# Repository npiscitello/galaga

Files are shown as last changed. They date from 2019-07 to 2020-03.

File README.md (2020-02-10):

# Sample Rate
If we run the system on the 8MHz internal clock and use 8-bit resolution PWM for the audio, we'll
have a sample rate of 8000000/256=31250 Hz. I used Audacity to prepare the audio files - project
rate of 31250, split into mono and delete one channel, then export the audio to unsigned 8 bit raw.

# FAT Driver
FatFS driver - see http://elm-chan.org/fsw/ff/00index_e.html (may take a while to load)

# KiCAD
Required libraries (may not be an all-inclusive list...):
 * custom library, bundled in this repo
 * Device
 * Connector
 * MCU_Microchip_ATmega
 * Amplifier_Audio
 * Regulator_Linear

# Random Number Generator
This project needs some way to decide which sound to play. The easy way out is
to just play one sound over and over, but I wanted more variety. I could rotate
over a list of sounds sequentially, but then I'd have to store which sound
played previously in the EEPROM and worry about wear leveling and all sorts of
mess, so I decided to just choose a random sound every time the chip starts up.
This also has the added bonus of not getting locked into a monotonous loop if
you want to play a few sounds in a row.

On the advice of a few threads over at AVRFreaks, I played around with using ADC
noise as an entropy source for a random number generator. I tried using the
internal temp sensor, but it ended up working much better to use ADC5, the pin
furthest from the GND pin. It probably didn't matter which pin I used (not that
I tested pin vs. pin performance), but it seemed like that was a free way to get
a little bit more noise on the line. That's a weird sentence to type, but noise
is desirable in this case!

The random number generator itself is dead simple - I read the two LSBs of the
ADC four times to fill an 8 bit unsigned int then just modulo that number with
the number of entries in my sound file array. That number is just an index into
that array and bam - random sound. See `code/main_code/sound_files.c` for the
implementation.

To test the randomness I cycled the chip 100 times and recorded the output of
the RNG. The histogram of the results is shown below - not the most even
distribution but certainly random enough for my purposes. This test also
doubled as a stability test, and I'm happy to report that it ran flawlessly,
with no errors or hiccups, all 100 times in a row!

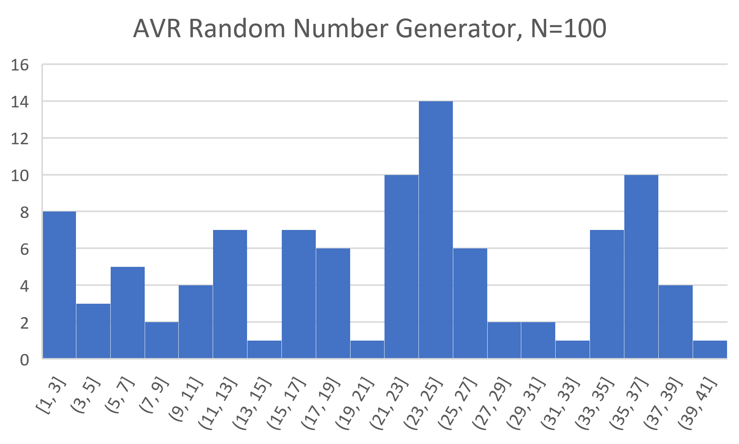
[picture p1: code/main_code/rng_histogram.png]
Histogram showing the results of 100 test runs of the RNG. The distribution is satisfactorily random.


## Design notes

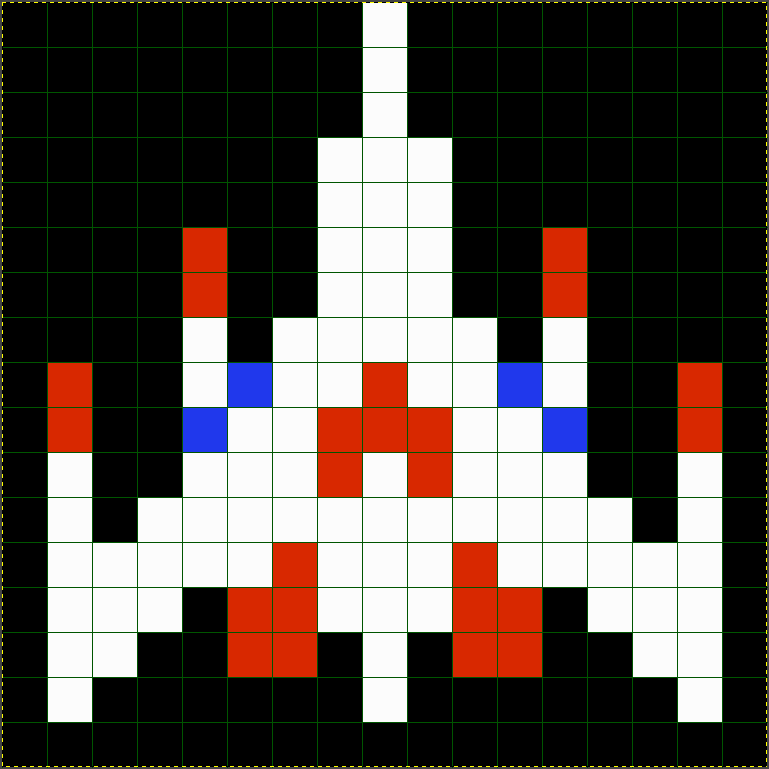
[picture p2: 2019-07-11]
design/sprite.png

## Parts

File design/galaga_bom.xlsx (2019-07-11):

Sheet: electrical
Description | Manufacturer | Mfr. P/N | Supplier | Sup. P/N | Price | Qty | Total | Notes | Link
Audio Amp | Texas Instruments | LM386N-4/NOPB | Mouser | 926-LM386N-4/NOPB | $1.01 | 5 | $5.05 | Audio amp - hook directly up to 9v (get a bunch, for other projects) | https://www2.mouser.com/ProductDetail/Texas-Instruments/LM386N-4-NOPB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
Speaker | CUI | CMS-35208N | Mouser | 490-CMS-35208N | $5.05 | 3 | $15.15 | Speaker - don't need anything special (order a couple, these are cool) | https://www2.mouser.com/ProductDetail/CUI/CMS-35208N
SD Breakout | SparkFun | BOB-00544 | Mouser | 474-BOB-00544 | $3.96 | 2 | $7.92 | microSD card breakout for holding audio files (order 2, useful to have on hand) | https://www2.mouser.com/ProductDetail/SparkFun/BOB-00544
Voltage Regulator | ST | LD1117V33 | Mouser | 511-LD1117V33 | $0.55 | 5 | $2.76 | 3v3 voltage regulator (order a few, always need power regulators) | https://www2.mouser.com/ProductDetail/STMicroelectronics/LD1117V33
8 pin socket | TE Connectivity | 1-2199298-2 | Mouser | 571-1-2199298-2 | $0.10 | 5 | $0.50 | I hate soldering bare chips (order to match amp quantity) | https://www.mouser.com/ProductDetail/TE-Connectivity/1-2199298-2?qs=fK8dlpkaUMtEKa4wabwOXQ%3d%3d
28 pin socket | TE Connectivity | 1-2199298-9 | Mouser | 571-1-2199298-9 | $0.71 | 10 | $7.10 | I hate soldering bare chips (order a bunch, I never seem to have any) | https://www.mouser.com/ProductDetail/TE-Connectivity/1-2199298-9?qs=fK8dlpkaUMumZ9haKKccEA%3d%3d
ATMEGA328 | Microchip/ATMEL |  | Mouser |  |  | 0 | $0.00 | Need one, but I already have about a billion
2 pos terminal | TE Connectivity | 282834-2 | Mouser | 571-282834-2 | $0.52 | 15 | $7.83 | Always need these, never have them | https://www2.mouser.com/ProductDetail/TE-Connectivity/282834-2
3 pos terminal | TE Connectivity | 282834-3 | Mouser | 571-282834-3 | $1.11 | 15 | $16.65 | Always need these, never have them | https://www2.mouser.com/ProductDetail/TE-Connectivity/282834-3
10uf cap | Vishay | MAL203038109E3 | Mouser | 594-2222-030-38109 | $0.56 | 3 | $1.69 | For package sizing ref; ordering so I know exactly what I'm using | https://www2.mouser.com/ProductDetail/Vishay-BC-Components/MAL203038109E3
250uf cap | Vishay | TVA1161 | Mouser | 75-TVA1161 | $3.43 | 2 | $6.86 | For package sizing ref; ordering so I know exactly what I'm using | https://www2.mouser.com/ProductDetail/Vishay-Sprague/TVA1161
0.47uf cap | Vishay | K474K20X7RF5TH5 | Mouser | 594-K474K20X7RF5TH5 | $0.36 | 2 | $0.72 | For package sizing ref; ordering so I know exactly what I'm using | https://www2.mouser.com/ProductDetail/Vishay-BC-Components/K474K20X7RF5TH5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
0.047uf cap | Vishay | K473K10X7RF5UH5 | Mouser | 594-K473K10X7RF5UH5 | $0.14 | 2 | $0.28 | For package sizing ref; ordering so I know exactly what I'm using | https://www2.mouser.com/ProductDetail/Vishay-BC-Components/K473K10X7RF5UH5
 |  |  |  |  |  |  | $0.00
 |  |  |  |  |  |  | $72.51 | TOTAL

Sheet: mechanical
Part | Qty | Color
bottom_shell | 1 | white
top_shell | 1 | white (portions to be painted blue)
blaster | 4 | trans red
left_booster | 1 | trans red
right_booster | 1 | trans red
cockpit | 1 | trans red
fin | 1 | white
9v battery clip | 1 | doesn't matter | https://www.thingiverse.com/thing:580694/files

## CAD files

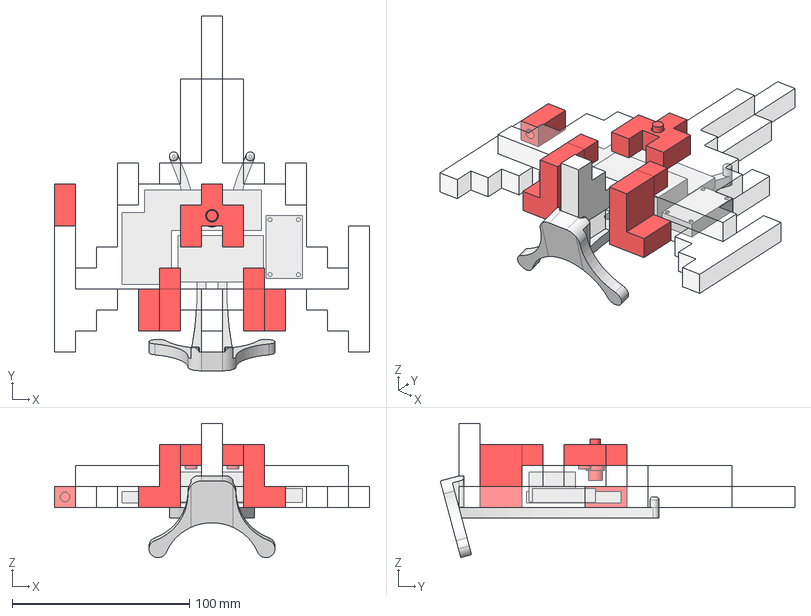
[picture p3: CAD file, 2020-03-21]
design/galaga_shell.FCStd
177.8 x 200.2 x 75.7 mm
bottom_shell
speaker
battery
top_shell
blaster
left_booster
right_booster
cockpit
fin
board
button
stand_back
stand_base

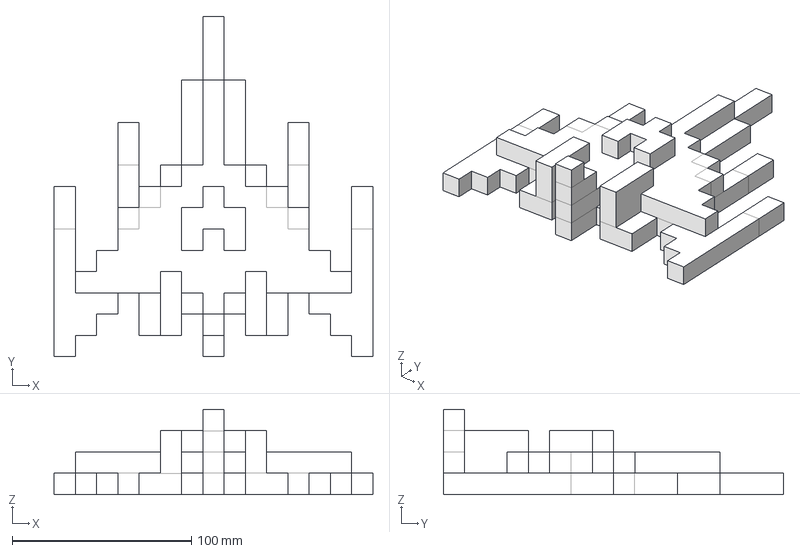
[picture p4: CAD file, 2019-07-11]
design/galaga.FCStd
177.8 x 189.7 x 47.4 mm

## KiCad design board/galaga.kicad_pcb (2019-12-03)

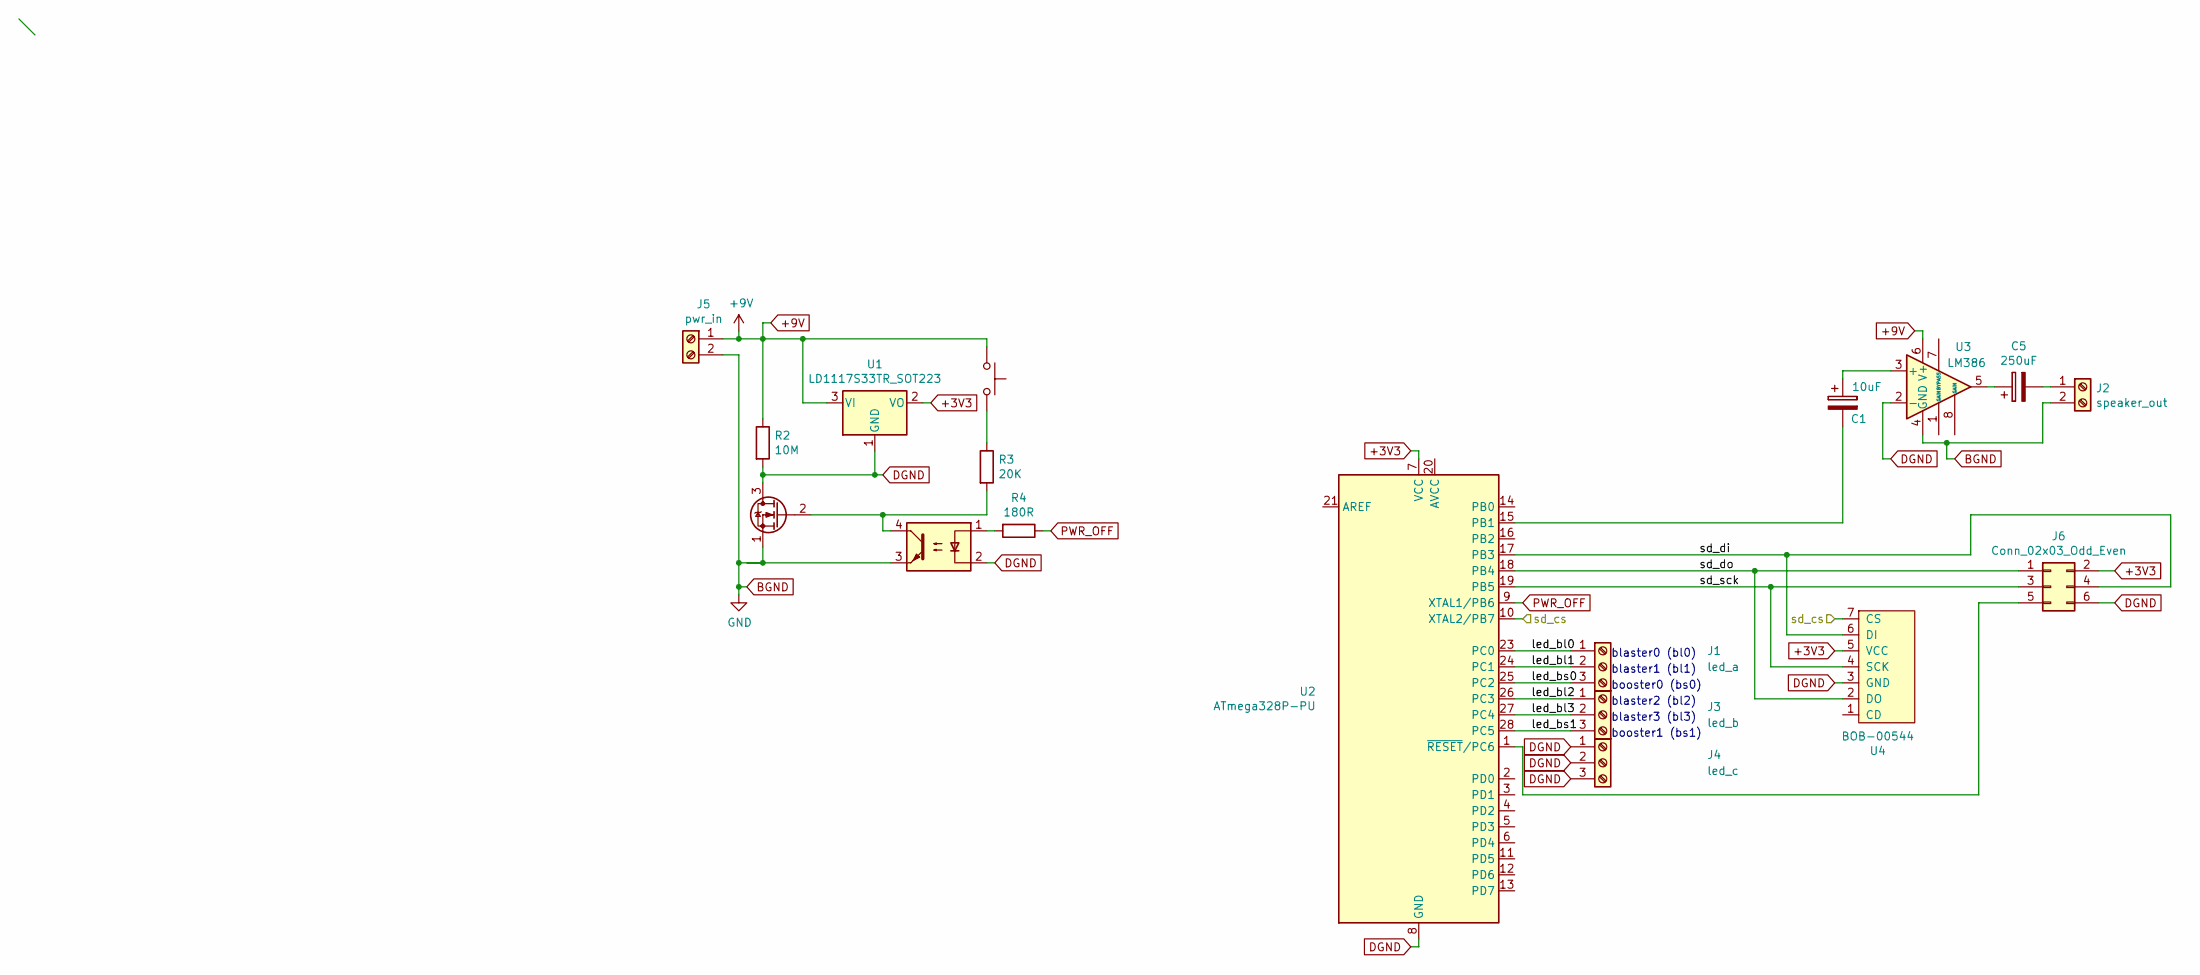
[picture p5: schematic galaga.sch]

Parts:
C1: 10uF; CP_Axial_L10.0mm_D6.0mm_P15.00mm_Horizontal
C5: 250uF; CP_Axial_L20.0mm_D10.0mm_P26.00mm_Horizontal
J1: led_a; TerminalBlock_TE_282834-3_1x03_P2.54mm_Horizontal
J2: speaker_out; TerminalBlock_TE_282834-2_1x02_P2.54mm_Horizontal
J3: led_b; TerminalBlock_TE_282834-3_1x03_P2.54mm_Horizontal
J4: led_c; TerminalBlock_TE_282834-3_1x03_P2.54mm_Horizontal
J5: pwr_in; TerminalBlock_TE_282834-2_1x02_P2.54mm_Horizontal
J6: Conn_02x03_Odd_Even; PinHeader_2x03_P2.54mm_Vertical
Q1: 2N7000; TO-220-3_Vertical
R2: 10M; R_Axial_DIN0207_L6.3mm_D2.5mm_P2.54mm_Vertical
R3: 20K; R_Axial_DIN0207_L6.3mm_D2.5mm_P2.54mm_Vertical
R4: 180R; R_Axial_DIN0207_L6.3mm_D2.5mm_P2.54mm_Vertical
SW1: SW_Push; TerminalBlock_TE_282834-2_1x02_P2.54mm_Horizontal
U1: LD1117S33TR_SOT223; TO-220-3_Vertical
U2: ATmega328P-PU; DIP-28_W7.62mm
U3: LM386; DIP-8_W7.62mm
U4: BOB-00544; PinHeader_1x07_P2.54mm_Vertical
U5: LTV-817M; DIP-4_W10.16mm

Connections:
+3V3: J6.2, U1.2 (VO), U2.7 (VCC), U4.5 (VCC)
+9V: J5.1, R2.1, SW1.1, U1.3 (VI), U3.6 (V+)
/led_bl0: J1.1, U2.23 (PC0)
/led_bl1: J1.2, U2.24 (PC1)
/led_bl2: J3.1, U2.26 (PC3)
/led_bl3: J3.2, U2.27 (PC4)
/led_bs0: J1.3, U2.25 (PC2)
/led_bs1: J3.3, U2.28 (PC5)
/sd_di: J6.4, U2.17 (PB3), U4.6 (DI)
/sd_do: J6.1, U2.18 (PB4), U4.2 (DO)
/sd_sck: J6.3, U2.19 (PB5), U4.4 (SCK)
BGND: J2.2, J5.2, Q1.1 (S), U3.4 (GND), U5.3
DGND: J4.1, J4.2, J4.3, J6.6, Q1.3 (D), R2.2, U1.1 (GND), U2.8 (GND), U2.22 (GND), U3.2 (-), U4.3 (GND), U5.2
unnamed: C1.1, U3.3 (+)
unnamed: C1.2, U2.15 (PB1)
unnamed: C5.1, U3.5
unnamed: C5.2, J2.1
unnamed: J6.5, U2.1 (~RESET~/PC6)
unnamed: Q1.2 (G), R3.2, U5.4
unnamed: R3.1, SW1.2
unnamed: R4.2, U5.1
PWR_OFF: R4.1, U2.9 (XTAL1/PB6)

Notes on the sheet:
blaster0 (bl0)
blaster1 (bl1)
blaster2 (bl2)
blaster3 (bl3)
booster0 (bs0)
booster1 (bs1)

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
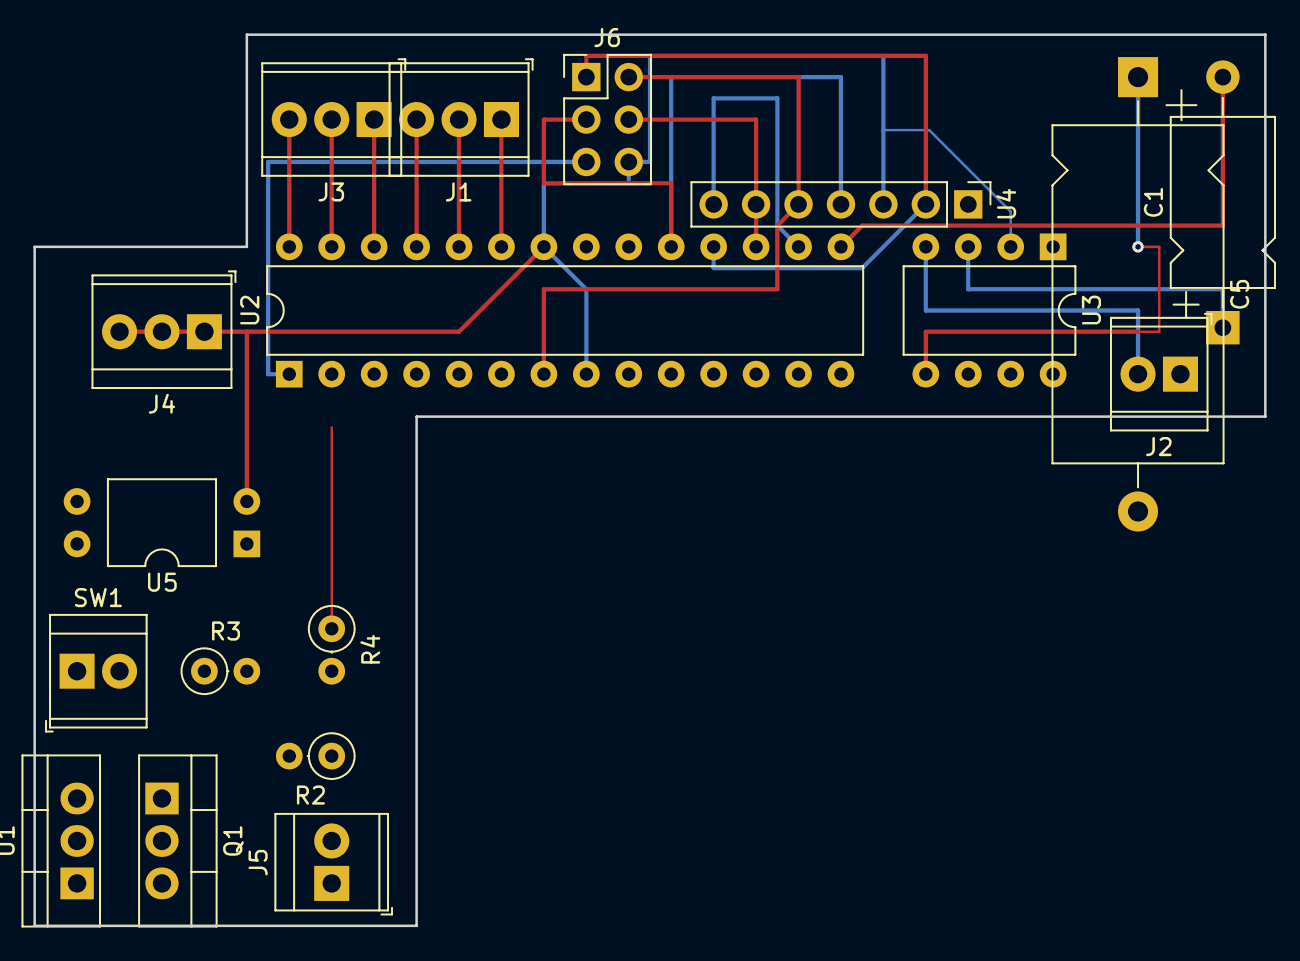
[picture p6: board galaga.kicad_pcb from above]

Board: 2 copper layers, 73.7 x 53.3 mm, 18 parts (0 on the bottom side), 23 nets.

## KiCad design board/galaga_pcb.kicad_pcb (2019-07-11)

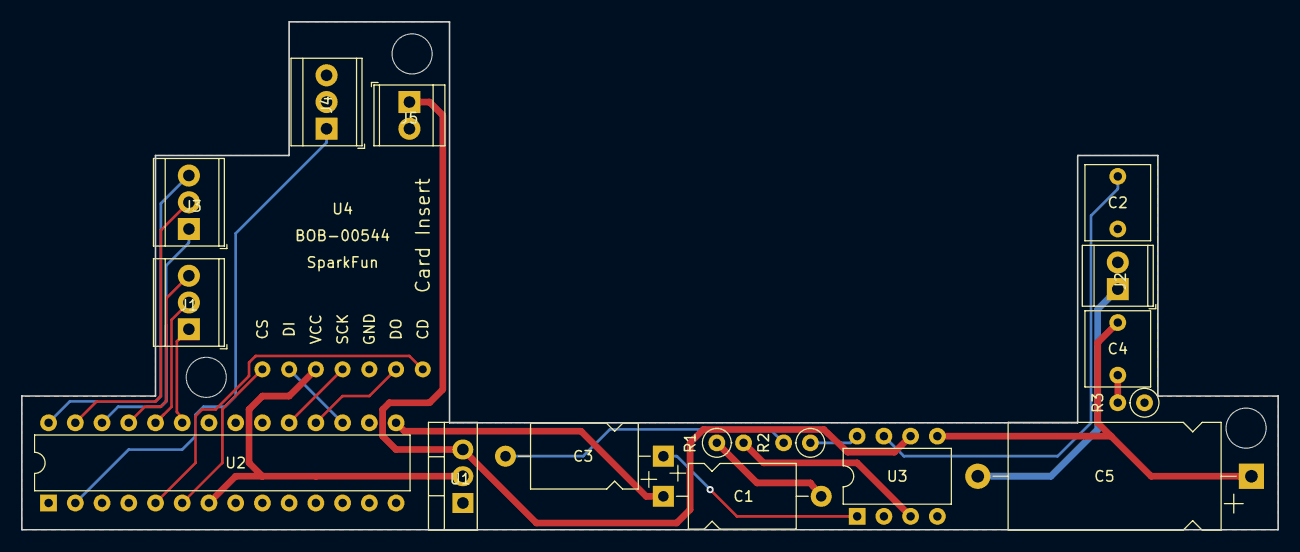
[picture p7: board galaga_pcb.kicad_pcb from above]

Board: 2 copper layers, 119.4 x 48.3 mm, 17 parts (0 on the bottom side), 25 nets.

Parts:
C1, C3: 10uF; CP_Axial_L10.0mm_D6.0mm_P15.00mm_Horizontal
C2: 0.5uF; C_Rect_L7.0mm_W6.0mm_P5.00mm
C4: 0.05uF; C_Rect_L7.0mm_W6.0mm_P5.00mm
C5: 250uF; CP_Axial_L20.0mm_D10.0mm_P26.00mm_Horizontal
J1: led_a; TerminalBlock_TE_282834-3_1x03_P2.54mm_Horizontal
J2: speaker_out; TerminalBlock_TE_282834-2_1x02_P2.54mm_Horizontal
J3: led_b; TerminalBlock_TE_282834-3_1x03_P2.54mm_Horizontal
J4: led_c; TerminalBlock_TE_282834-3_1x03_P2.54mm_Horizontal
J5: pwr_in; TerminalBlock_TE_282834-2_1x02_P2.54mm_Horizontal
R1, R2: 10k (max); R_Axial_DIN0207_L6.3mm_D2.5mm_P2.54mm_Vertical
R3: 10; R_Axial_DIN0207_L6.3mm_D2.5mm_P2.54mm_Vertical
U1: LD1117S33TR_SOT223; TO-220-3_Vertical
U2: ATmega328P-PU; DIP-28_W7.62mm
U3: LM386; DIP-8_W7.62mm
U4: BOB-00544; bob-00544

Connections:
+3V3: U1.2, U2.7, U4.5
+9V: J5.1, U1.3, U3.6
/led_bl0: J1.1, U2.23
/led_bl1: J1.2, U2.24
/led_bl2: J3.1, U2.26
/led_bl3: J3.2, U2.27
/led_bs0: J1.3, U2.25
/led_bs1: J3.3, U2.28
/sd_cd: U2.5, U4.1
/sd_cs: U2.6, U4.7
/sd_di: U2.17, U4.6
/sd_do: U2.18, U4.2
/sd_sck: U2.19, U4.4
GND: C2.1, J2.2, J4.2, J4.3, J5.2, R3.1, U1.1, U2.8, U2.22, U3.2, U3.4, U4.3
unnamed: C1.1, U2.15
unnamed: C1.2, R1.1
unnamed: C2.2, U3.7
unnamed: C3.1, U3.1
unnamed: C3.2, R2.2
unnamed: C4.1, C5.1, U3.5
unnamed: C4.2, R3.2
unnamed: C5.2, J2.1
unnamed: J4.1, U2.2
unnamed: R1.2, U3.3
unnamed: R2.1, U3.8

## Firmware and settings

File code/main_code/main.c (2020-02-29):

#include <avr/io.h>
#include <avr/interrupt.h>
#include <stdlib.h>
#include <avr/pgmspace.h>
#include "pff.h"
#include "diskio.h"
#include "utils.h"
#include "sound_files.h"

// how many bits of resolution used by the DAC
#define PWM_RESOLUTION 0x00FF

// how many bytes are in each of the double buffers
#define BUFFER_SIZE 512

// definition for the LED bootup
// how many 33-millisecond ticks to wait before the LEDs change during an
// animation (12 is a little under 152 BPM, the tempo of the intro)
#define LED_BOOTUP_DELAY 3
// how many frames are in the bootup sequence (oneshot)
#define LED_BOOTUP_STEPS 4
// led frames - each byte gets masked and written to Port C.
// LSB is the far right blaster.
const uint8_t g_led_bootup_frames[] PROGMEM = {
  0x00, 0x0C, 0x2D, 0x3F
};

// definition for the LED animation
// how many 33-millisecond ticks to wait before the LEDs change during an
// animation (12 is a little under 152 BPM, the tempo of the intro)
#define LED_ANIMATION_DELAY 4
// how many frames are in the animation sequence (looping)
#define LED_ANIMATION_STEPS 6
// led frames - each byte gets masked and written to Port C.
// LSB is the far right blaster.
//const uint8_t g_led_animation_frames[] PROGMEM = {0x2A, 0x15};
const uint8_t g_led_animation_frames[] PROGMEM = {
  0x2C, 0x1C, 0x02, 0x0D, 0x0E, 0x10
};

// if an SD card op fails all we can do is try again
// <TODO> add logic in the final app to power off after 
// a certain number of failed ops in a row
#define TRY_SD_OP(A) while( A != FR_OK ) {}

volatile uint8_t flags = 0x00;
#define MSK_FLAG_SD_READING       0x01
#define MSK_FLAG_BUFFER_SWAPPED   0x02
#define MSK_FLAG_END_OF_FILE      0x04
#define MSK_FLAG_SD_READY         0x08



 /***********************\
|***** AUDIO AND DAC *****|
 \***********************/

// there's gotta be a better way to do this than using so many globals
// the active buffer with audio data
volatile uint8_t* g_buf_read;
// the secondary buffer being loaded with data from the SD card
volatile uint8_t* g_buf_load;
// which sample is currently being read from that sample buffer
volatile uint16_t g_sample_index = 0;



// this is the main DAC
void setup_dac(void) {
  // disable interrupts globally for setup
  cli();
  // set OC1A (PB1) to output
  set_mask(&DDRB, _BV(DDB1));
  // turn on timer 1
  clr_mask(&PRR, _BV(PRTIM1));

  // PWM setup
  // set pin behavior (non-inverted) and part of waveform mode (fast PWM, TOP=ICR1)
  TCCR1A = 0x00 | _BV(COM1A1) | _BV(WGM11);
  // set part of waveform mode (fast PWM, TOP=ICR1). Clock will be enabled later.
  TCCR1B = 0x00 | _BV(WGM13) | _BV(WGM12);
  // set TOP
  ICR1H = 0xFF & (PWM_RESOLUTION >> 8);
  ICR1L = 0xFF & (PWM_RESOLUTION);

  // waveform setup (load new value to OCR1A every TOP interrupt)
  // enable timer1 TOP interrupts and clear pending interrupts
  TIMSK1 = 0x00 | _BV(TOIE1);
  TIFR1 = 0xFF;
  // clear OCR1AH b/c we're only dealing with 8 bit for now
  OCR1AH = 0x00;

  // enable global interrupts
  sei();
  return;
}



// read a bunch of bytes from the SD card
void read_chunk( uint8_t* read_buf, uint16_t num_bytes ) {
  UINT bytes_read = 0;
  set_mask(&flags, MSK_FLAG_SD_READING);
  TRY_SD_OP( pf_read(read_buf, num_bytes, &bytes_read) );
  clr_mask(&flags, MSK_FLAG_SD_READING);

  if( bytes_read < num_bytes ) {
    set_mask(&flags, MSK_FLAG_END_OF_FILE);
  }
  return;
}



// pump out a sample. If the SD card is still filling the other buffer, idle
// on the current sample until its done.
ISR(TIMER1_OVF_vect) {
  OCR1AL = *(g_buf_read + g_sample_index);
  g_sample_index++;
  if( g_sample_index >= BUFFER_SIZE ) {
    if( flags & MSK_FLAG_SD_READING ) {
      g_sample_index--;
    } else {
      g_sample_index = 0;
      swap_buffers(&g_buf_read, &g_buf_load);
      set_mask(&flags, MSK_FLAG_BUFFER_SWAPPED);
    }
  }
}



void stop_PWM(void) {
  clr_mask(&TCCR1B, _BV(CS12) | _BV(CS11) | _BV(CS10));
}

void start_PWM(void) {
  // no prescaler for timer1 (DAC)
  set_mask(&TCCR1B, _BV(CS10));
}



 /**************************\
|***** LEDS AND FLASHING*****|
 \**************************/

// simulate a 16 bit timer (make sure an LED change triggers on first enable)
volatile uint8_t g_timer0_cycles = LED_ANIMATION_DELAY;
// which frame we're on
volatile uint8_t g_current_frame = 0;



void setup_leds( void ) {
  // LED pins are all output (even the one used for the ADC!)
  set_mask(&DDRC, _BV(DDC0) | _BV(DDC1) | _BV(DDC2) | 
      _BV(DDC3) | _BV(DDC4) | _BV(DDC5));

  // We're sourcing, so start all LED pins low
  clr_mask(&PORTC, _BV(PORTC0) | _BV(PORTC1) | _BV(PORTC2) |
      _BV(PORTC3) | _BV(PORTC4) | _BV(PORTC5));

  // see setup_dac function for details
  // prescaler set in the start_LED function
  cli();
  clr_mask(&PRR, _BV(PRTIM0));
  TIMSK0 = _BV(TOIE0);
  TIFR0 = 0xFF;
  sei();
  return;
}



ISR(TIMER0_OVF_vect) {
  if( !(flags & MSK_FLAG_SD_READY) ) {
    if( ++g_timer0_cycles > LED_BOOTUP_DELAY ) {
      g_timer0_cycles = 0;
      PORTC &= 0xC0;
      // avr compiler magic, YCM will complain
      PORTC |= pgm_read_byte(&(g_led_bootup_frames[g_current_frame])) & 0x3F;
      // we only want it to run once
      if( g_current_frame < LED_BOOTUP_STEPS - 1 ) {
        ++g_current_frame;
      }
    }
  } else {
    if( ++g_timer0_cycles > LED_ANIMATION_DELAY ) {
      g_timer0_cycles = 0;
      PORTC &= 0xC0;
      // avr compiler magic, YCM will complain
      PORTC |= pgm_read_byte(&(g_led_animation_frames[g_current_frame])) & 0x3F;
      if( ++g_current_frame >= LED_ANIMATION_STEPS ) {
        g_current_frame = 0;
      }
    }
  }
}



void stop_LED( void ) {
  clr_mask(&TCCR0B, _BV(CS02) | _BV(CS01) | _BV(CS00));
}

void start_LED( void ) {
  // make sure we trigger as soon as we enable
  TCNT0 = 0xFF;
  // 1024 prescaler for timer0 (LED flasher)
  set_mask(&TCCR0B, _BV(CS02) | _BV(CS00));
}



int main( void ) {

  // get the random filename before the LED output messes up the RNG
  char filename_buf[MAX_FILENAME_LEN];
  get_filename(filename_buf);

  setup_leds();
  start_LED();

  setup_dac();
  stop_PWM();

  // set up audio buffers
  g_buf_read = malloc(BUFFER_SIZE);
  g_buf_load = malloc(BUFFER_SIZE);
  if( (g_buf_read == 0) || (g_buf_load == 0) ) {
    // I don't know how to recover from a malloc error
    // shut off and try again next time!
    clr_mask(&PORTB, _BV(PORTB6));
  }

  // set PB6 to output and set high to keep SSR latched
  // we don't do this in the beginning in case the chip browns-out and resets as
  // the board turns off - putting it a handful of instructions down means it's
  // still quick enough to be 'instantaneous' to humans but not fast enough to
  // accidentally trigger and re-latch the SSR as the board is turning off.
  set_mask(&DDRB, _BV(DDB6));
  set_mask(&PORTB, _BV(PORTB6));

  // mount SD card
  FATFS fs;
  TRY_SD_OP( pf_mount( &fs ) );

  // load the sound file we'll be playing
  TRY_SD_OP( pf_open(filename_buf) );
  read_chunk( (uint8_t*)g_buf_load, BUFFER_SIZE );

  // switch the LEDs from the bootup sequence to the animation sequence
  set_mask(&flags, MSK_FLAG_SD_READY);
  g_current_frame = 0;

  // kick off audio
  swap_buffers(&g_buf_read, &g_buf_load);
  start_PWM();

  // make super duper sure we don't miss the end of file flag
  while(!(flags & MSK_FLAG_END_OF_FILE)) {
    // load new data every time the buffers swap
    if( flags & MSK_FLAG_BUFFER_SWAPPED ) {
      read_chunk( (uint8_t*)g_buf_load, BUFFER_SIZE );
      clr_mask(&flags, MSK_FLAG_BUFFER_SWAPPED);
    }
  }

  // un-latch the SSR
  clr_mask(&PORTB, _BV(PORTB6));
  return 0;
}

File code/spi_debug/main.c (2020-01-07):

#include <avr/io.h>
#include <avr/pgmspace.h>
#include "usart.h"

// SPI pins and such
#define CS_LOW()	PORTB &= ~_BV(PORTB7)	/* Set CS low */
#define	CS_HIGH()	PORTB |=  _BV(PORTB7)	/* Set CS high */
#define	IS_CS_LOW	!(PINB & _BV(PINB7))	/* Test if CS is low */

#define FCLK_SLOW() SPCR |= _BV(SPR1) | _BV(SPR0)   /* Set slow clock (F_CPU / 64) */
#define FCLK_FAST() SPCR &= ~_BV(SPR1) & ~_BV(SPR0)   /* Set fast clock (F_CPU / 2) */



// USART debug messages
#define LEN_STARTUP 13
const char PROGMEM startup[] = "\r\n\r\nstartup\r\n";

#define LEN_INIT_S 12
const char PROGMEM init_s[] = "init start\r\n";
#define LEN_INIT 7
const char PROGMEM init[] = "init\r\n";
#define LEN_INIT_E 10
const char PROGMEM init_e[] = "init end\r\n";

#define LEN_XMIT_S 12
const char PROGMEM xmit_s[] = "xmit start\r\n";
#define LEN_XMIT 6
const char PROGMEM xmit[] = "xmit\r\n";
#define LEN_XMIT_E 10
const char PROGMEM xmit_e[] = "xmit end\r\n";

#define LEN_RCV_S 11
const char PROGMEM rcv_s[] = "rcv start\r\n";
#define LEN_RCV 5
const char PROGMEM rcv[] = "rcv\r\n";
#define LEN_RCV_E 9
const char PROGMEM rcv_e[] = "rcv end\r\n";

#define LEN_LOOP 6
const char PROGMEM loop[] = "loop\r\n";



void init_spi(void) {
  transmit_string_flash(init_s, LEN_INIT_S);

  // outputs - B2 must be output, otherwise the floating input
  // pops the chip out of SPI Master mode!
  DDRB |= _BV(DDB7) | _BV(DDB3) | _BV(DDB5) | _BV(DDB2);

  // turn on and configure SPI peripheral
  PRR &= ~_BV(PRSPI);
  SPCR = _BV(SPE) | _BV(MSTR);
  SPSR = _BV(SPI2X);

  // gotta go fAST
  FCLK_FAST();

  transmit_string_flash(init_e, LEN_INIT_E);
}

void xmit_spi(uint8_t d) {
  transmit_string_flash(xmit_s, LEN_XMIT_S);
  SPDR = d;
  //loop_until_bit_is_set(SPSR, SPIF);
  while(!(SPSR & (1 << SPIF))) {}
  transmit_string_flash(xmit_e, LEN_XMIT_E);
}

uint8_t rcv_spi(void) {
  transmit_string_flash(rcv_s, LEN_RCV_S);
  xmit_spi(0xFF);
  transmit_string_flash(rcv_e, LEN_RCV_E);
  return SPDR;
}



int main(void) {
  init_usart0();
  transmit_string_flash(startup, LEN_STARTUP);

  init_spi();
  // similar construct as in the petitFATFS code
  for(uint8_t n= 10; n; n--) {
    transmit_string_flash(loop, LEN_LOOP);
    rcv_spi();
  }
}

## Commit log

2019-02-01 playing around with waveform generation
    We're gonna need to clock very, very fast - with 8 bit PCM at a 44100 Hz
    sample rate, we still need upwards of an 11 MHz system clock. With an
    8MHz clock, we can get a sample rate of 31250 tops. Maybe that's close
    enough for a 32000 Hz export? I'll try it and see...
2019-02-01 tried to get a waveform working...won't do it. need a scope.
    [main.c]
2019-02-01 interrupt still doesn't seem to be firing...maybe try with a different timer?
    [main.c]
2019-02-03 audio works, but not with the interrupt...
2019-02-03 RTFM. The interrupt vector macro is TIMER1_OVF_vect, not TIM1_OVF_vect.
2019-02-13 found FAT driver
2019-02-17 stubbed out low-level driver funcs for fatfs
2019-03-13 took avr mmc sample; got it to compile, still need to tweak it for this project
2019-03-18 added SPI clock macros
2019-07-06 tried to hack SD card together, getting a 'FR_NOT_READY' when calling 'f_mount' - the hardware implementation is definitely wrong.
    [main.c, mmc_avr_spi.c]
2019-07-11 adding all the physical design files
    [galaga.FCStd, galaga.kicad_pcb, galaga.sch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]
2019-07-13 timer was messed up (what's new?) but I think there's still a driver issue
    [main.c]
2019-07-13 prepping to switch to petit ffs - we'll see if it works better
2019-07-13 quick and dirty, doesn't work :(
    [avr_mmcp.c, main.c]
2019-07-13 tweaking, but it's still not working
    [avr_mmcp.c]
2019-07-13 it works now!!!
    Turns out, the guy who wrote this knows his own code better than me. Go
    figure. Changed the commands back and used the macros to wait for the
    SPI writes to finish and we're off to the races!
2019-07-22 used the fastest SPI clock and SD card mount is pretty quick. Might throw in an external crystal and bump the system clock to 16MHz if it turns out that's still too slow
    [avr_mmcp.c]
2019-07-22 LED test file works!
2019-07-31 it works! It wasn't actually throwing an error, I just wrote my error handler wrong. No _BV macros!
    [main.c]
2019-08-01 fixed loop: wasn't clearing the end of file flag
    [main.c]
2019-09-03 got UART debug comms working!
2019-09-06 added self-power-off hardware to schematic
    [galaga.sch]
2019-09-06 added self-power-off function test. Plot twist, it works!
2019-09-06 rearranged components to support using perfboard instead of a manufactured PCB. I think it also uses the space better?
    [galaga_shell.FCStd]
2019-09-06 started laying out board - doesn't have to be perfect (cuz it's perfboard) and there's some vertical room I'm playing with
    [galaga.sch, galaga_perfboard.kicad_pcb, galaga_shell.FCStd]
2019-12-03 changed SD CS pin to PORTB7 for better board layout
    [galaga.kicad_pcb, galaga.sch, galaga_pcb.kicad_pcb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]
2020-01-06 added self power-off test code
2020-01-07 revamped power and amp circuits, going back to breadboard testing before circuit construction
    [galaga.sch, galaga_route_v2.kicad_pcb, galaga_shell.FCStd]
2020-01-07 seems like SPI isn't working as expected - SPIF flag doesn't seem to get set
    [avr_mmcp.c, main.c]
2020-01-07 can't find the SPI issue - gonna do a minimum test case
    [avr_mmcp.c]
2020-01-07 fixed! needed to make the SS pin output
    Floating input was knocking the chip out of master mode.
    https://www.avrfreaks.net/forum/spif-flag-strange-behavior
    [avr_mmcp.c, main.c]
2020-01-07 fixed EOF and SD card op logic
    [main.c]
2020-01-10 finished the board, worked first shot!
    [galaga.sch, galaga_route_v2.kicad_pcb, galaga_shell.FCStd]
2020-01-11 let button come up into cockpit more
    [galaga_shell.FCStd]
2020-01-21 untested ADC 'random' number generator
2020-01-21 The package is coming together!
    Random doesn't really work, it seems to alternate between two numbers,
    but it might be a hardware setup issue. Still, it makes noise!
    [avr_mmcp.c, main.c, sound_files.c]
2020-01-30 fixed poweroff - one line!!!!! -_-
    Random is still having trouble - it seems like it's sorta getting kinda
    random stuff, but it's a little too consistent for my taste. I'll have
    to do some testing.
    [galaga.sch]
2020-01-30 Hopefully fixed no power off bug
    I moved the power latch later in the setup sequence - my theory is that
    the chip was browning out when the power pin brought the power down,
    jumping to the reset vector (without fully resetting), and running main
    again. Since the (nearly) first instruction in main was to latch the
    power on, the power stayed on. Moving the latch instruction to right
    before the first buffer fill should still be quick enough that a human
    button press will be latched but slow enough that a brownout partial
    reset cannot re-latch the power. Only testing will tell.......
    [main.c, sound_files.c]
2020-01-30 testing random function
    It's working - the reason it seemed like it was locking up was that one
    of my filenames was too long; I fixed that and it hits every time now.
    It's still a little too 'consistent' for my liking, but humans aren't
    too good at true randomness so <shrug>. I'll search around for other
    ways to generate 'randomness' on an AVR, but if I need to stick with
    this, I'll just artificially weight the sounds I like better by putting
    them in the table multiple times.
    [main.c, sound_files.c]
2020-02-10 RNG tweaked, tested, and working!
    All that's really left now is to make the lights flash and assemble
    everything. Making the while loop break at the end of file flag instad
    of polling seems to have fixed the no-power-off issue - it powered off
    perfectly 100 times in a row!
    [galaga.sch]
2020-02-29 led flashing demo implemented, broke rng...
    [galaga.sch, galaga_route_v2.kicad_pcb]
2020-02-29 implemented programmable LED animation, fixed rng
    [main.c]
2020-02-29 added led bootup, added a nicer animation
2020-03-01 added stand to CAD model
    [galaga_shell.FCStd]
2020-03-21 project finished - cleanup commit
    [galaga_shell.FCStd]
